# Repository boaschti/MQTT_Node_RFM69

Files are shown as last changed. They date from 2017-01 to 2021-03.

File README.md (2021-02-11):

# RFM69 JSON (Battery)Multisensor
 
This project is a multisensor node based on a Atmega328 and RFM69 radio. The Sensor is a ultraLowPower(0.1uA) device supplied from 1.8V to 3.6V.
 
You can connect the node with the [Gateway](https://github.com/boaschti/MQTT_WLan_RFM69_Gateway) via MQTT to your home automation.
Just download .hex and flash it with avr studio. 
Fuses for use without ext crystal are: low_fuses=0xd2 high_fuses=0xd1 extended_fuses=0xfe (extended_fuses=0xff = BrownOut off = UltraLowPower)
Fuses for use with ext crystal are: low_fuses=0xff high_fuses=0xd1 extended_fuses=0xfe (extended_fuses=0xff = BrownOut off = UltraLowPower). And cut the cooper between RFM and crystal inputs (atmega).

### Board
The board has
- 7 GPIOs including 4 analog inputs
- spi connector
- 3 Leds
- Micro step up via capacitor
- 2 levelshifter or nFet to power sensors ect
- dimensions are 19x22mm
 
The board you can order [here](https://www.itead.cc/) or other PCB Services. You also can send a Email, my price is 0,80€.
 
### Software Features
 
**Supported sensors**
- BME280 BMP280
- DS18b20 (in future)
- HC-SR05 (in future)
- every switch (pir (hc-sr501), touch sensors (TTP223), reed kontakt, hall Sensor (DRV5032FADBZT) ect)
- light sensor (LDR)
- every analog Sernsor (rain sensor, plant sensor, ect)
- S0 energy counter
 
**Supported aktors**
- every aktor which can be used on a DIO
- watchdog can clear/set DOs
- ssd1306 displays
- any electronic thermostat with encoder to set temperature
 
**Software**
- very simple configuration via [Gateway](https://github.com/boaschti/MQTT_WLan_RFM69_Gateway)
- communication encrypted
- free configurable via radio, no flash programming needed, every node has the same software
- interrupts wakes the node
- the DO can be cleared/set by internal watchdog
- counters on each DI
- programmable sleep times
- programmable sensor measure times
- programmable watchdog times
- and more... you can see [here](https://github.com/boaschti/MQTT_WLan_RFM69_Gateway/blob/master/pictures/nodeConfig.jpg)
 
### Home Assistant config
note: use different command_topic (anyChar). The topic from broker to node is rfmOut/networkId/nodeId/anyChar, the topic from node to broker is rfmIn/networkId/nodeId/jsonValue
 
**Temperature, humidity, pressure, battery, rssi, counter(p_0-p_6)**
```
sensor:
  - platform: mqtt
    state_topic: 'rfmIn/146/254/Bt'
    name: 'Temperature'
    unit_of_measurement: '°C'
    value_template: '{{ value_json.Bt }}'
  - platform: mqtt
    state_topic: 'rfmIn/146/254/Bh'
    name: 'Humidity'
    unit_of_measurement: '%'
    value_template: '{{ value_json.Bh }}'
  - platform: mqtt
    state_topic: 'rfmIn/146/254/Bp'
    name: 'Pressure'
    unit_of_measurement: 'hPa'
    value_template: '{{ value_json.Bp }}'
  - platform: mqtt
    state_topic: 'rfmIn/146/254/batt'
    name: 'Battery'
    unit_of_measurement: 'mV'
    value_template: '{{ value_json.batt }}'
  - platform: mqtt
    state_topic: 'rfmIn/146/254/c_4'
    name: 'Counter'
    value_template: '{{ value_json.c_4 }}'
  - platform: mqtt
    state_topic: 'rfmIn/146/254/rxInfo'
    name: 'RSSI'
    value_template: '{{ value_json.rssi }}'
```
 
**Switches (input) p_0-p_6**
```
binary_sensor:
  - platform: mqtt
    state_topic: "rfmIn/146/250/p_5"
    name: "PIR"
    payload_on: "1"
    payload_off: "0" 
    device_class: opening
    value_template: '{{ value_json.p_5 }}'
```
 
**input slider to set temperature of digital termostat**
```
# Define input_slider
input_slider:
  target_temp:
    name: Target Heater Temperature Slider
    min: 5
    max: 30
    step: 1
    unit_of_measurement: step 
    icon: mdi:target
 
automation:
   # This automation script runs when the target temperature slider is moved.
   # It publishes its value to the same MQTT topic it is also subscribed to
   # The message is json format
  - alias: Temp slider moved
    trigger:
      platform: state
      entity_id: input_slider.target_temp
    action:
      service: mqtt.publish
      data_template:
        topic: "rfmOut/146/250/2"
        retain: true
        payload: "{\"t_0\":\"{{ states.input_slider.target_temp.state | int }}\"}"
```
 
**Outputs p_0-p_6**
```
switch:
  - platform: mqtt
    name: "Test Switch"
    state_topic: "rfmIn/146/254/p_4"
    command_topic: "rfmOut/146/254/1"
    payload_on: "{\"p_4\":\"1\"}"
    payload_off: "{\"p_4\":\"0\"}"
    optimistic: false
    retain: true
```
 
**Display**
```
switch:
  - platform: mqtt
    name: "Test Switch"
    command_topic: "rfmOut/146/254/1"
    payload_on: "{\"d_0\":\"Switch ON\"}"
    payload_off: "{\"d_0\":\"Switch OFF\"}"
    optimistic: true
    retain: true
```

**Watchdog**
'''
input_boolean:
  trigger_wd_terrasse:
    name: Watchdog Terrasse
    initial: off
  switch_terrasse_m:
    name: Terrasse m
    initial: off

automation:
  - alias: Trigger Watchdog
    trigger:
      platform: state
      entity_id: input_boolean.trigger_wd_terrasse
      to: "on"
    action:
      - service: mqtt.publish
        data_template:
          topic: "rfmOut/146/116/wd"
          retain: false
          payload: "{\"wd_0\":\"0\"}"
      - service: input_boolean.turn_off
        data: 
          entity_id: input_boolean.trigger_wd_terrasse    
  
  - alias: Trigger Watchdog auto
    trigger:
      platform: time
      seconds: 59
    condition:
      condition: or
      conditions:
        - condition: state
          entity_id: input_boolean.switch_terrasse_vl
          state: "on"
        - condition: state
          entity_id: input_boolean.switch_terrasse_m
          state: "on"
    action:
      service: input_boolean.turn_on
      data: 
        entity_id: input_boolean.trigger_wd_terrasse  
        
  - alias: Start Timer Terrasse m
    trigger:
      platform: state
      entity_id: input_boolean.switch_terrasse_m
      to: "on"
    action:
      service: mqtt.publish
      data_template:
        topic: "rfmOut/146/116/p_5"
        retain: false
        payload: "{\"wd_0\":\"0\", \"p_5\":\"1\"}"

  - alias: Schalte Ventil Terrasse m aus
    trigger:
      platform: state
      entity_id: input_boolean.switch_terrasse_m
      to: "off"
    action:
      service: mqtt.publish
      data_template:
        topic: "rfmOut/146/116/p_5"
        retain: false
        payload: "{\"p_5\":\"0\"}"
'''
### Hardware
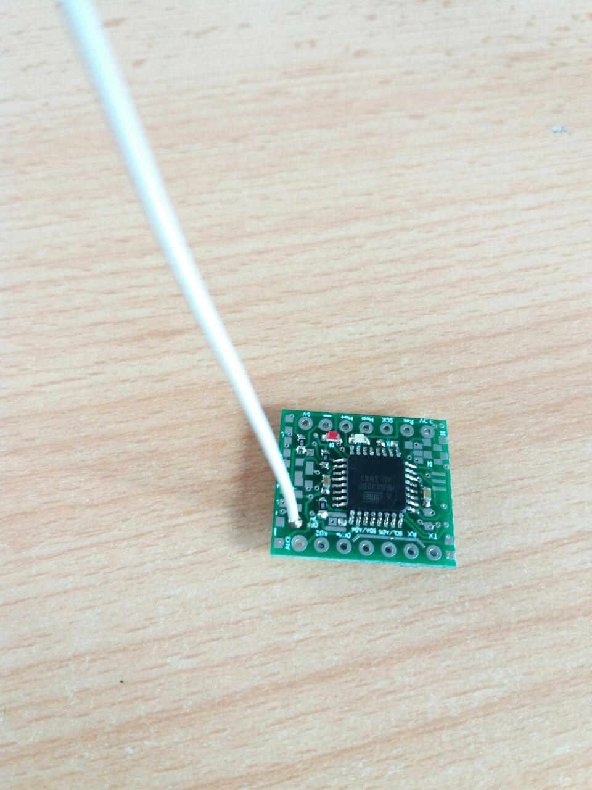
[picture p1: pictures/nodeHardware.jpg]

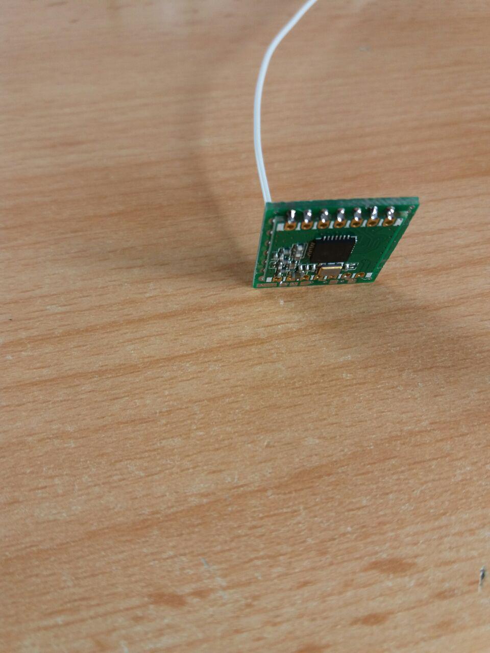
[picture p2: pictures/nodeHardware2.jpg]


### Housing

**3AAA_PIR_Node**
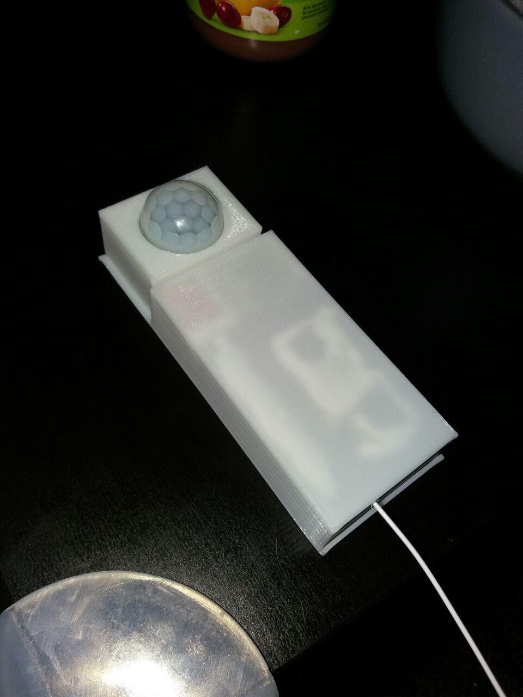
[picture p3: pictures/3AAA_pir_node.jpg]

 
**3AAA_PIR_Node inside, modification PIR (nFet or diode bat46 4148 ect)**

 
**2AAA_Node**
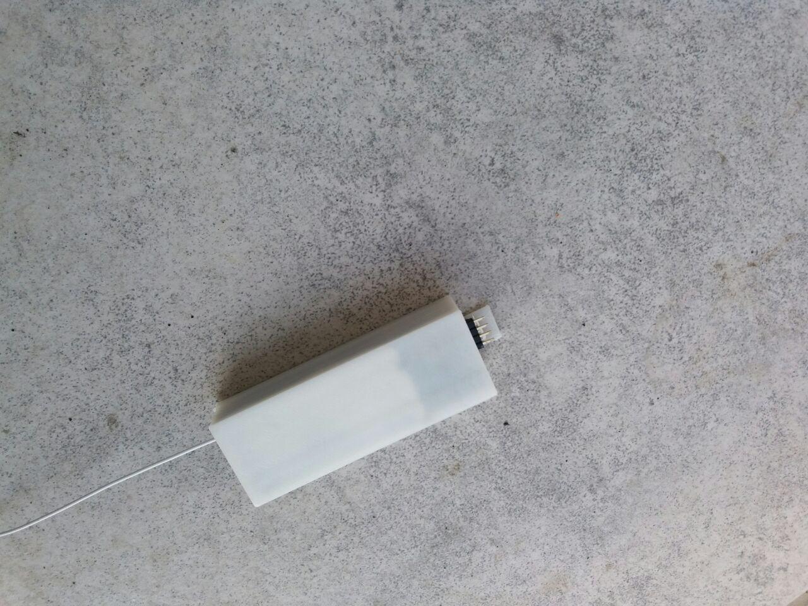
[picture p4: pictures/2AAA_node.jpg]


**2AAA_Node_inside**
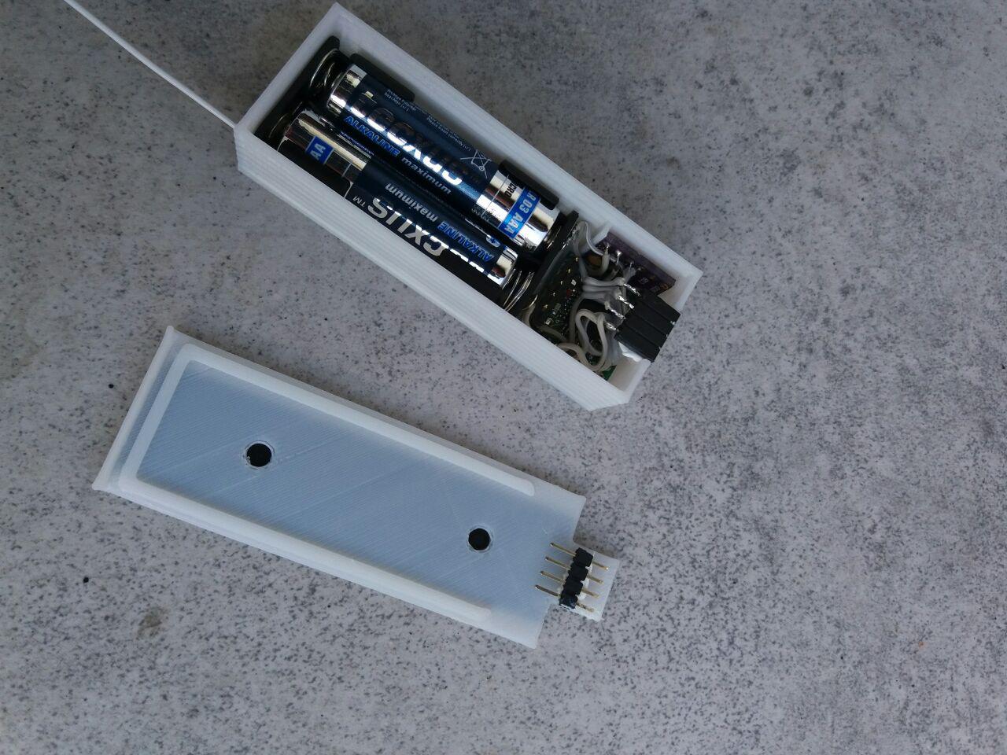
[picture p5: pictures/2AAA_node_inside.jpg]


**Display_housing**
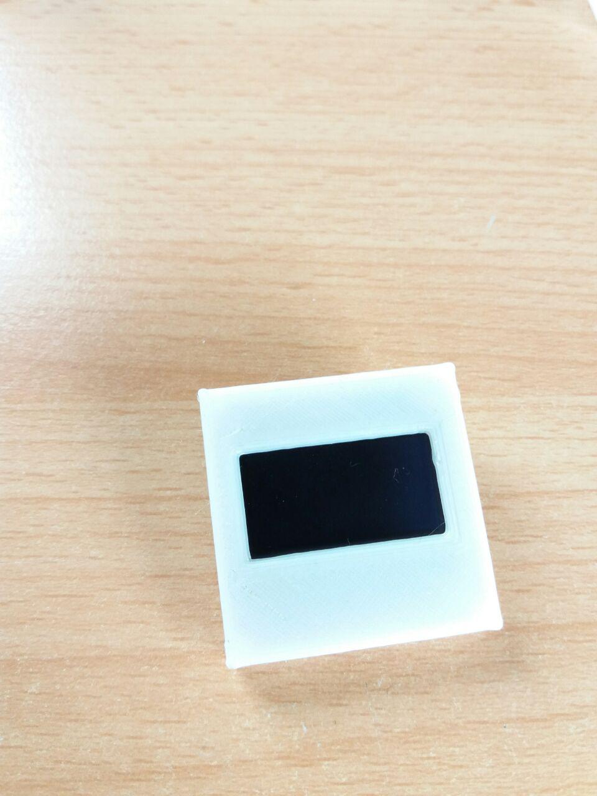
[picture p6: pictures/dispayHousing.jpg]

 
**Mini_Node_1**
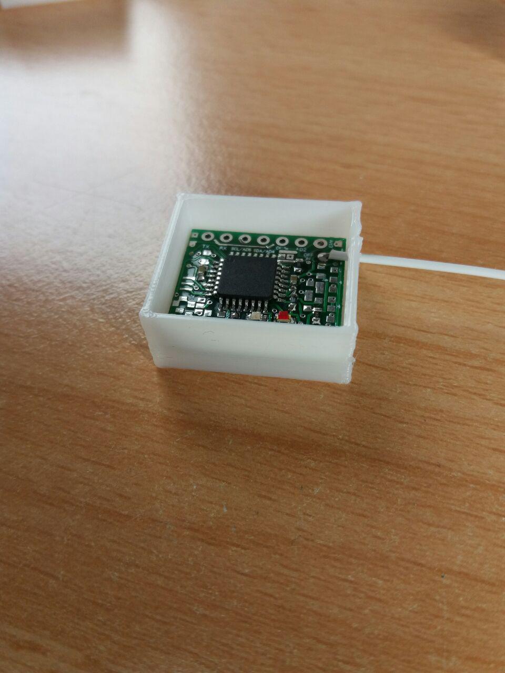
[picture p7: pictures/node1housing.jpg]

 
**Mini_Node_2 use the shown BME/BMP Sensor!**
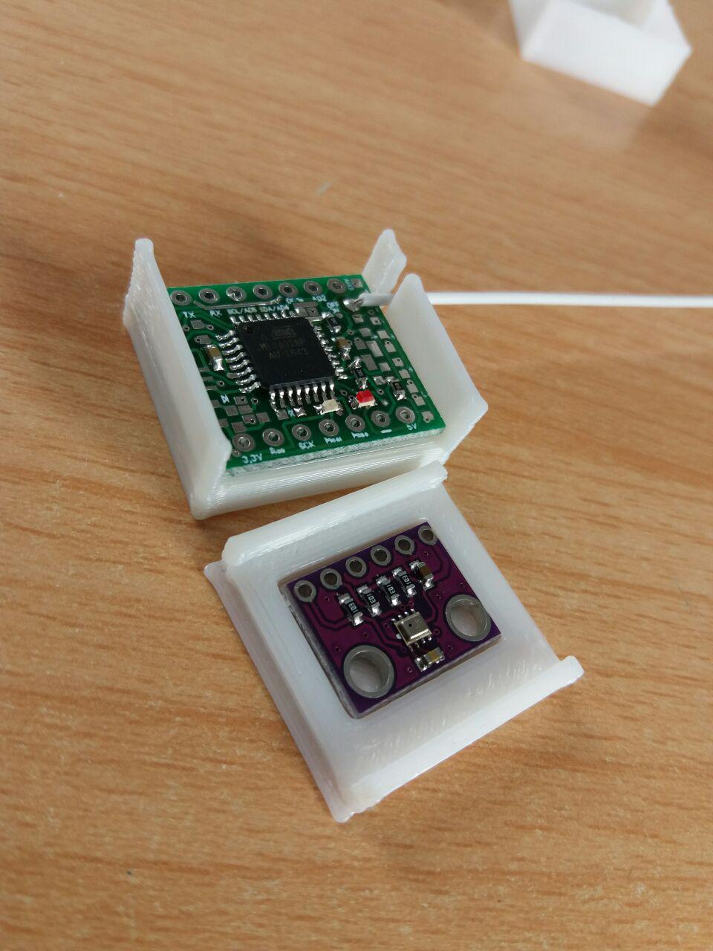
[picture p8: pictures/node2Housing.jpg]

 
**Modification_Display**
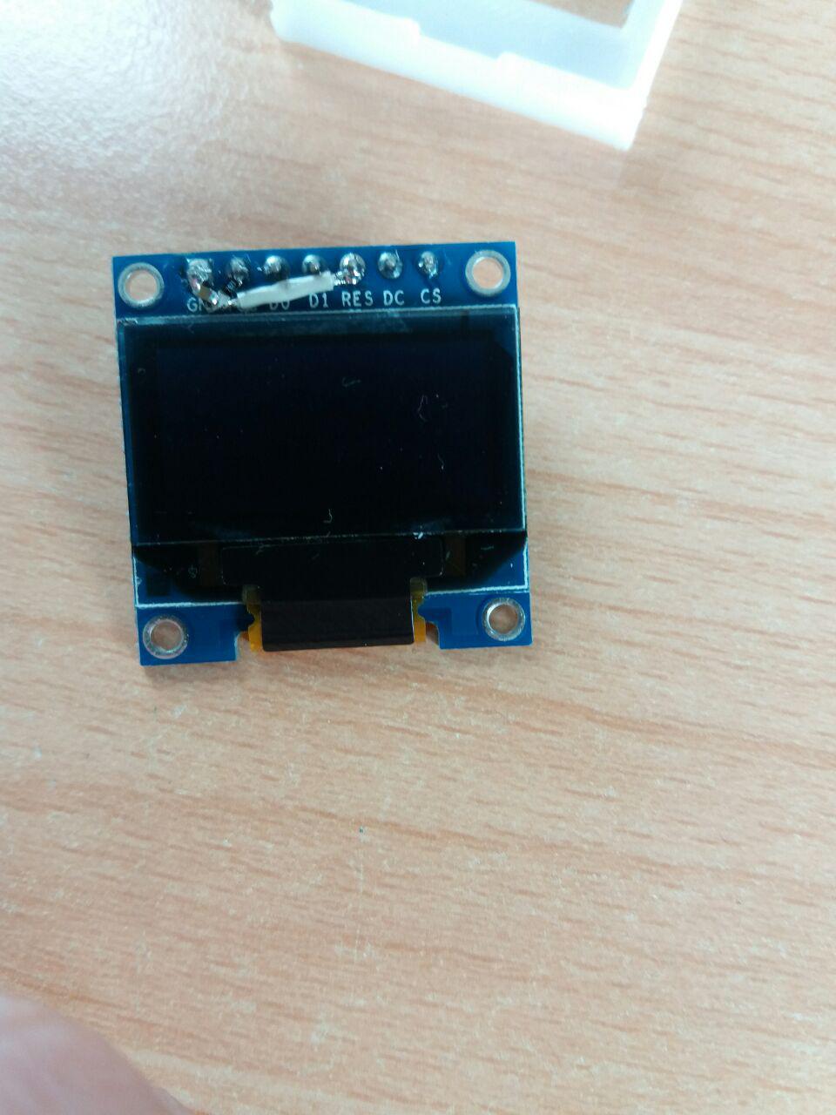
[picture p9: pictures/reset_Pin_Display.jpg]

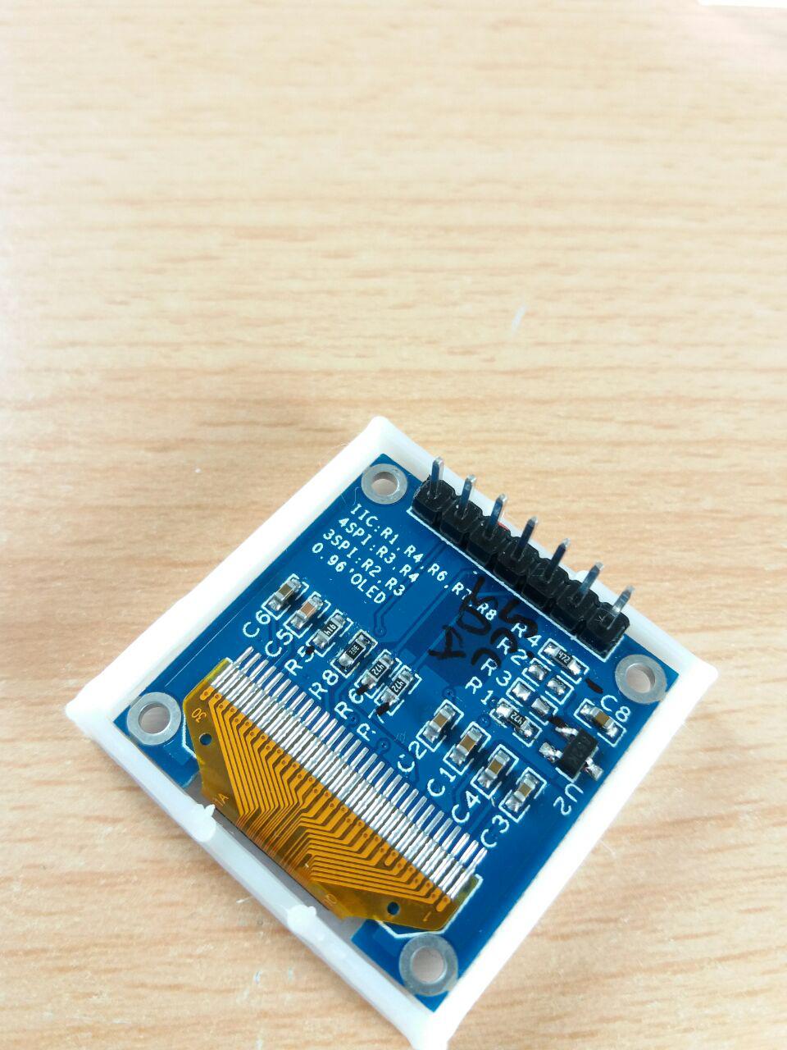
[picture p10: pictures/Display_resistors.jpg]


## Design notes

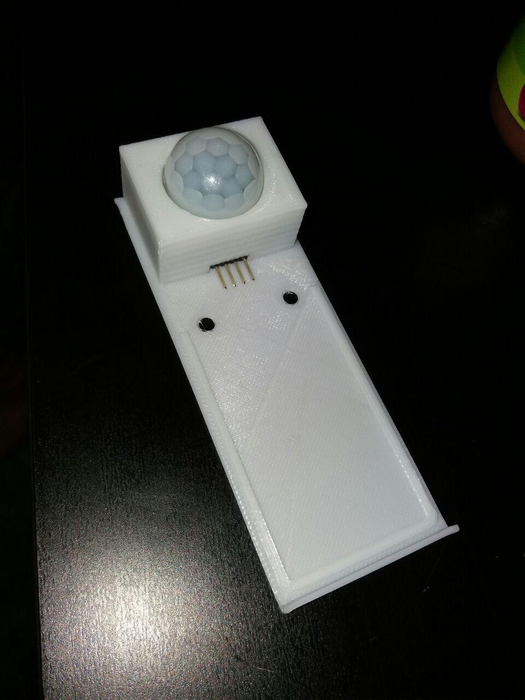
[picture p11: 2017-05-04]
pictures/pir_node.jpg

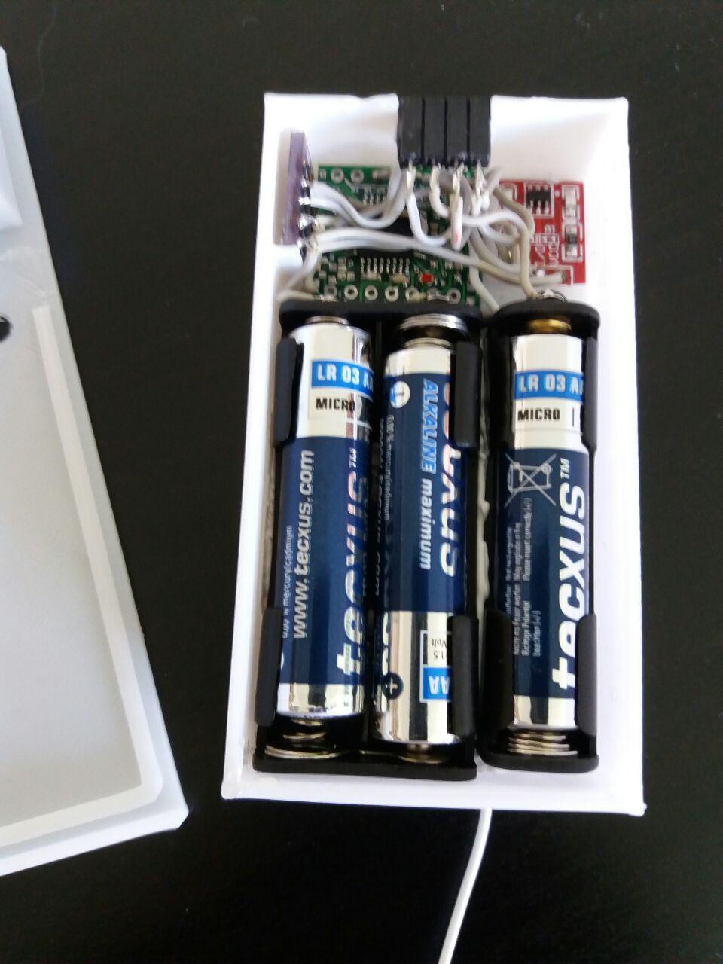
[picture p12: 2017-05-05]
pictures/3AAA_pir_node_inside2.jpg

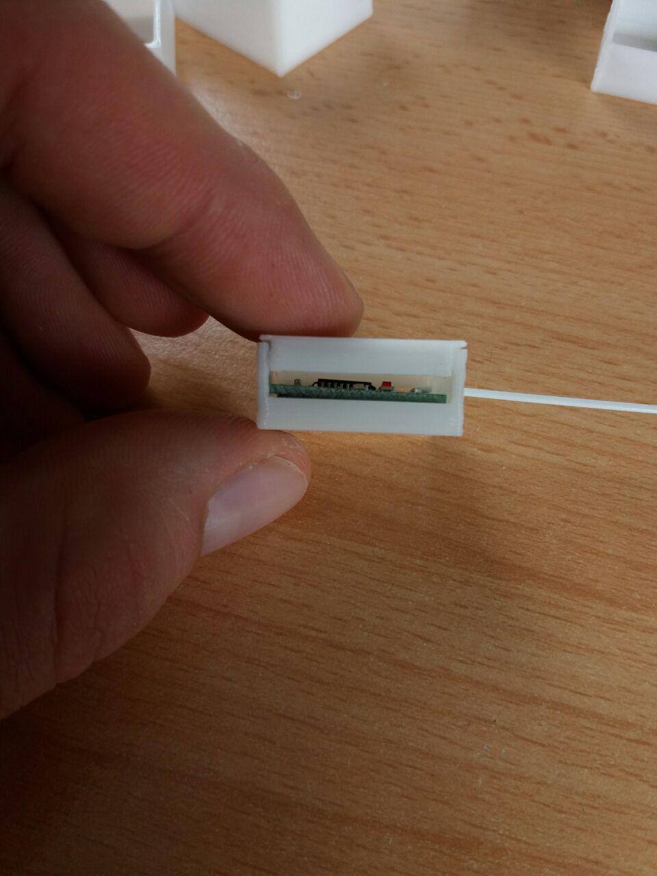
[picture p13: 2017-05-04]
pictures/node2Housing2.jpg

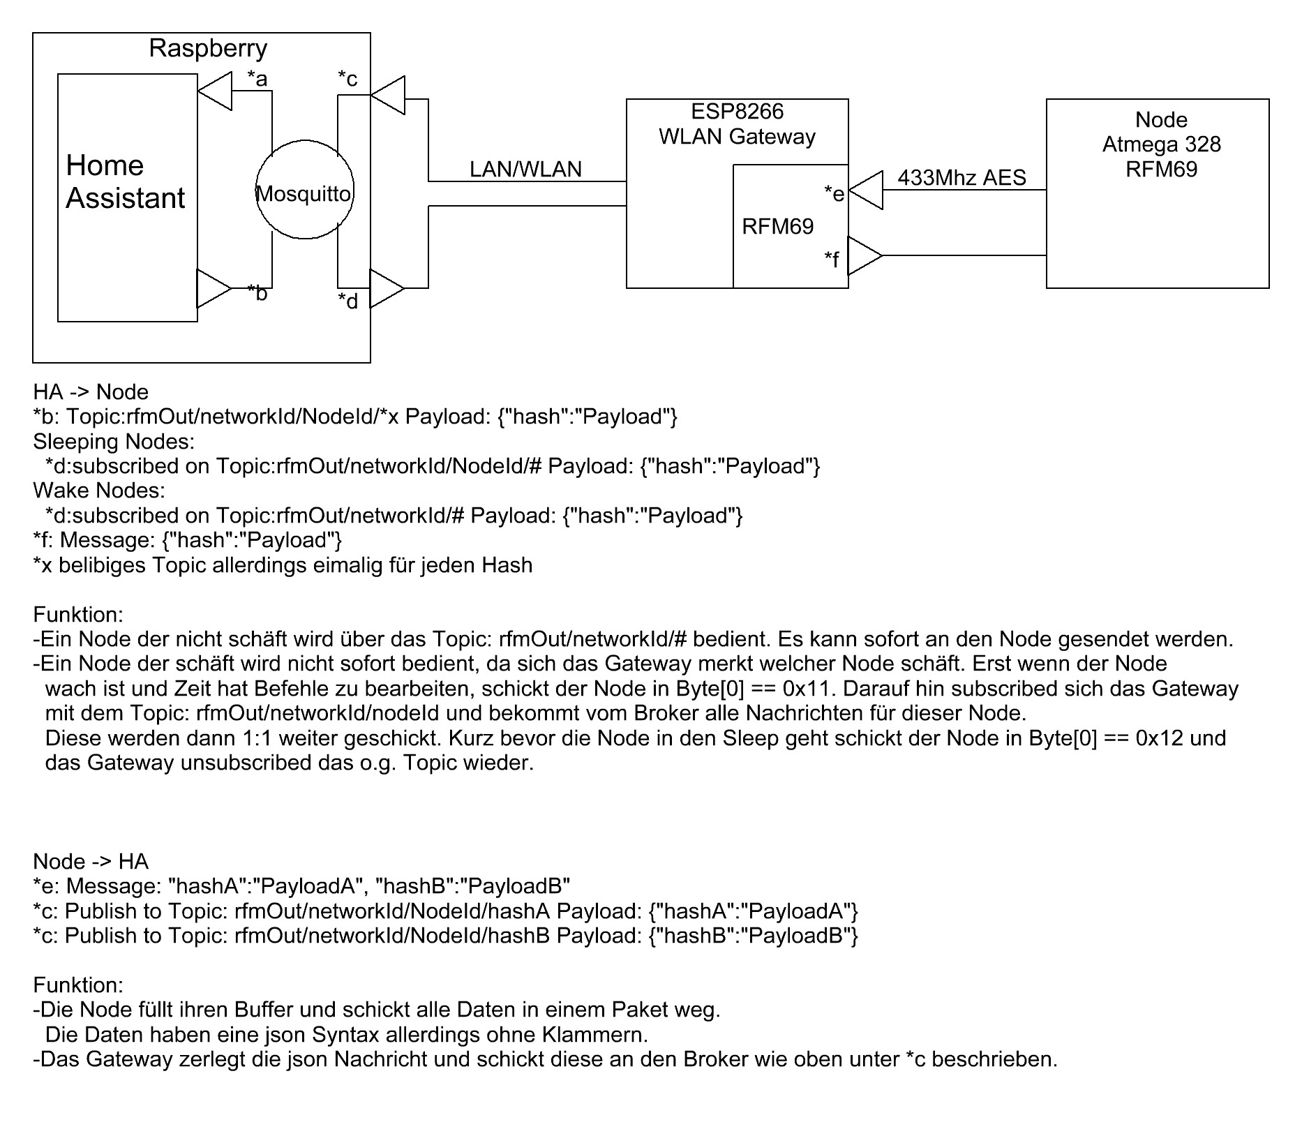
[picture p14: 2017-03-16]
Kommunikation.JPG

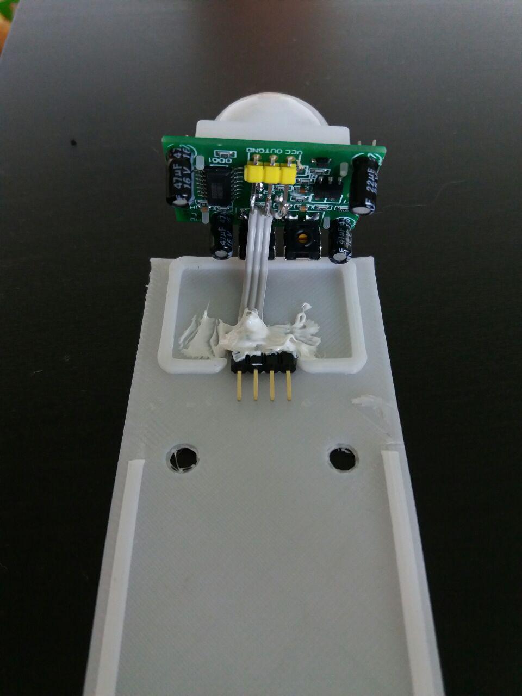
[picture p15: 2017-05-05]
pictures/pir.jpg

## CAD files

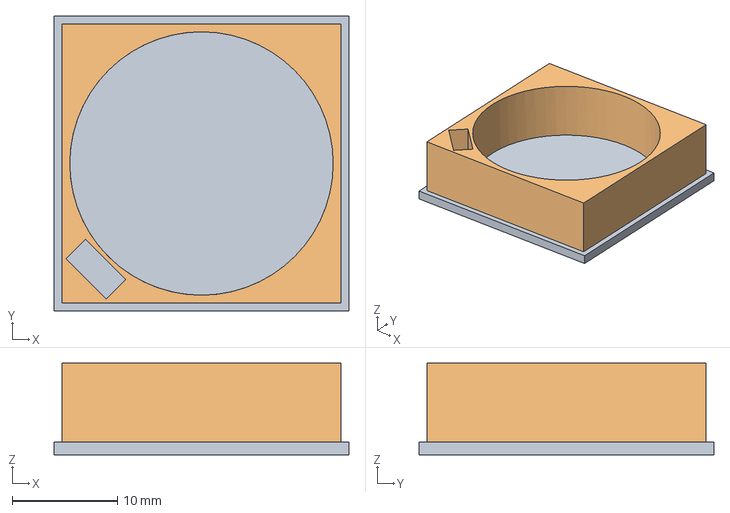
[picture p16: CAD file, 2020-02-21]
Housing/Deckel_CR2477_Node.FCStd
28.0 x 28.0 x 8.70 mm
Würfel001

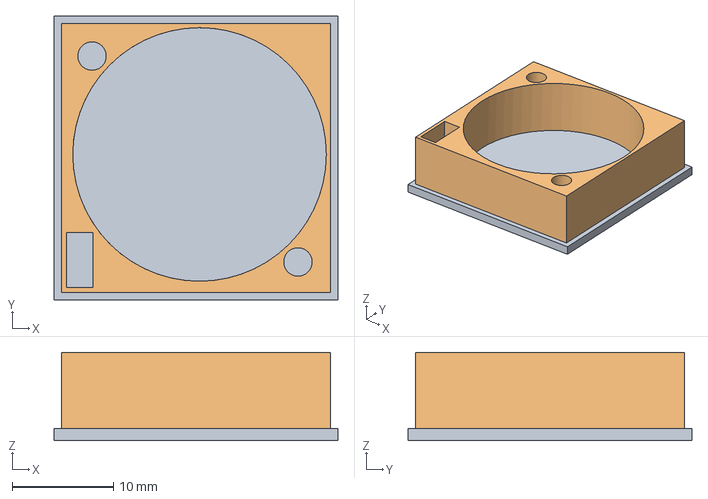
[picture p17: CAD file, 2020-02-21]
Housing/Deckel_CR2477_Node2.FCStd
28.0 x 28.0 x 8.70 mm
Würfel001

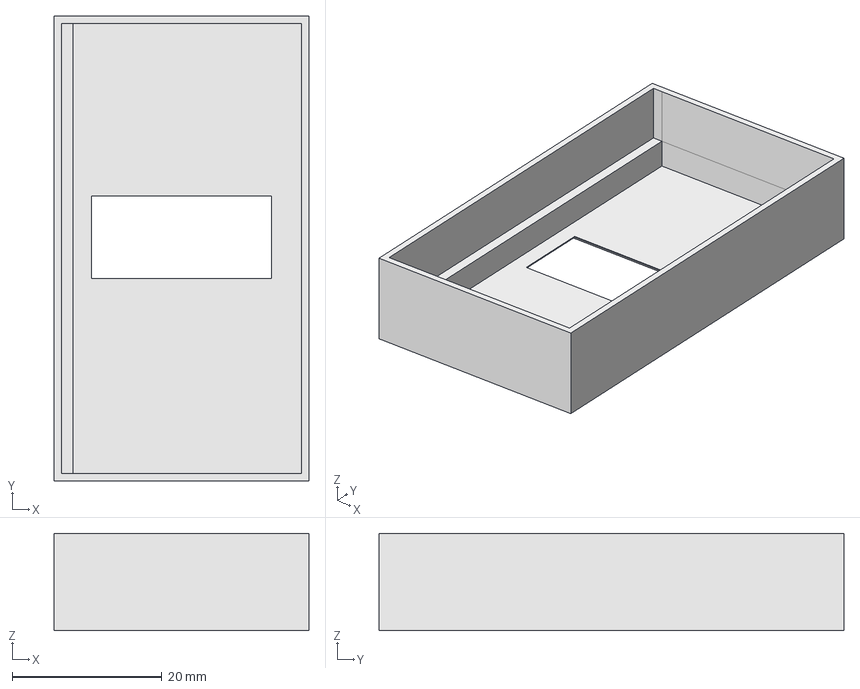
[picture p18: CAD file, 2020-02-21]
Housing/MaxiNodeDisp_Touch.FCStd
34.0 x 62.0 x 13.0 mm

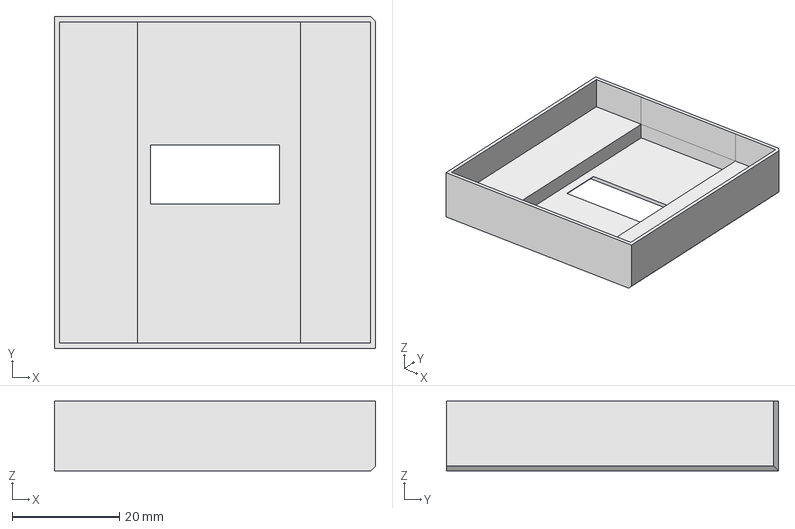
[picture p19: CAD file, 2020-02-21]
Housing/MaxiNodeDisp_Touch_AAA.FCStd
60.0 x 62.0 x 13.0 mm

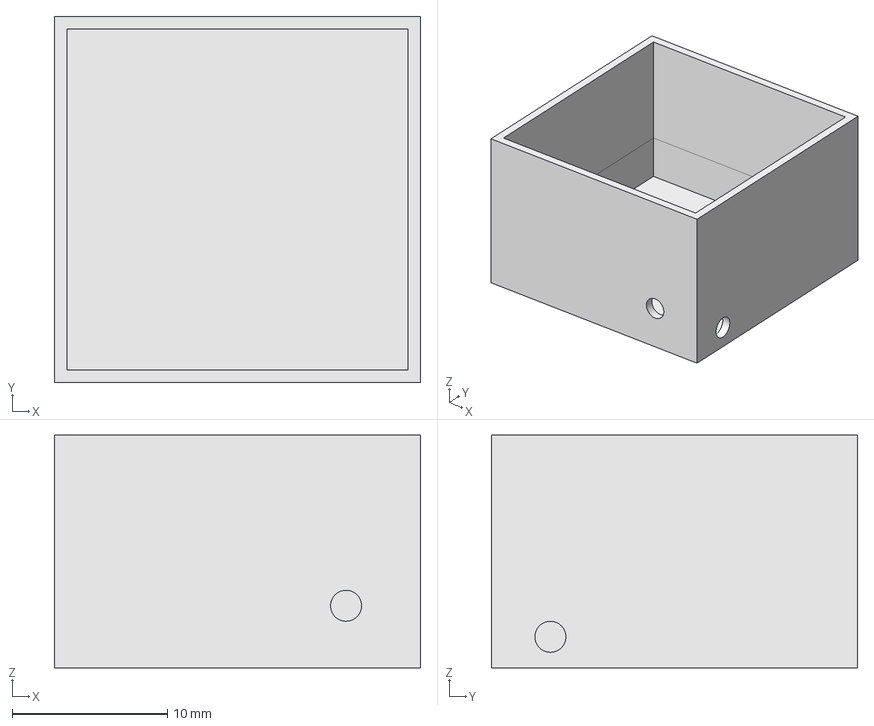
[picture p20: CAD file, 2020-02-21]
Housing/Gehause Node3.FCStd
23.6 x 23.6 x 15.0 mm

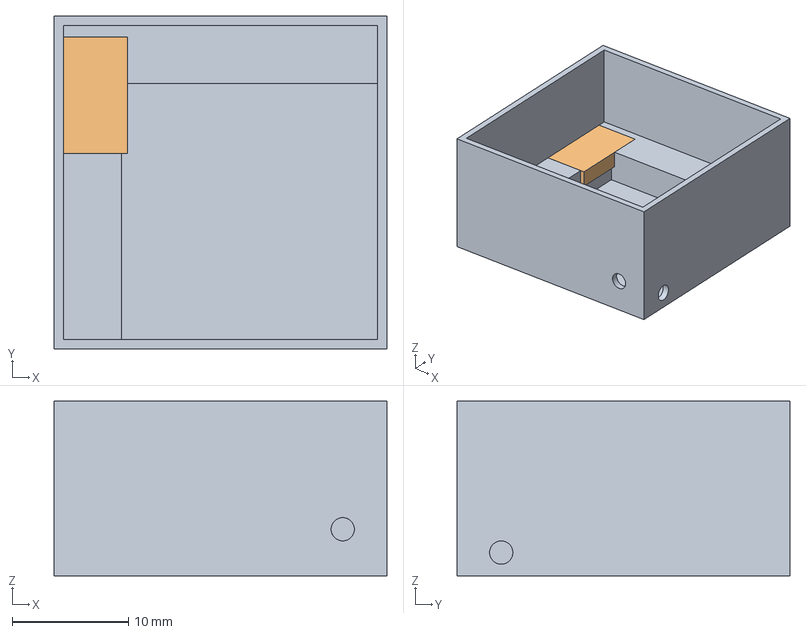
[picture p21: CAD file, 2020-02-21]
Housing/Gehause_CR2477_Node.FCStd
28.6 x 28.6 x 15.0 mm
Würfel003

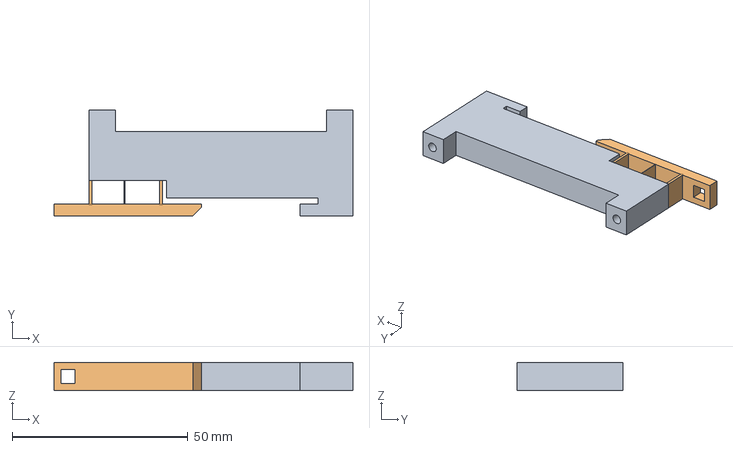
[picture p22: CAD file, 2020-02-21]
Housing/Halter Hutschine Relais.FCStd
85.0 x 30.0 x 8.00 mm

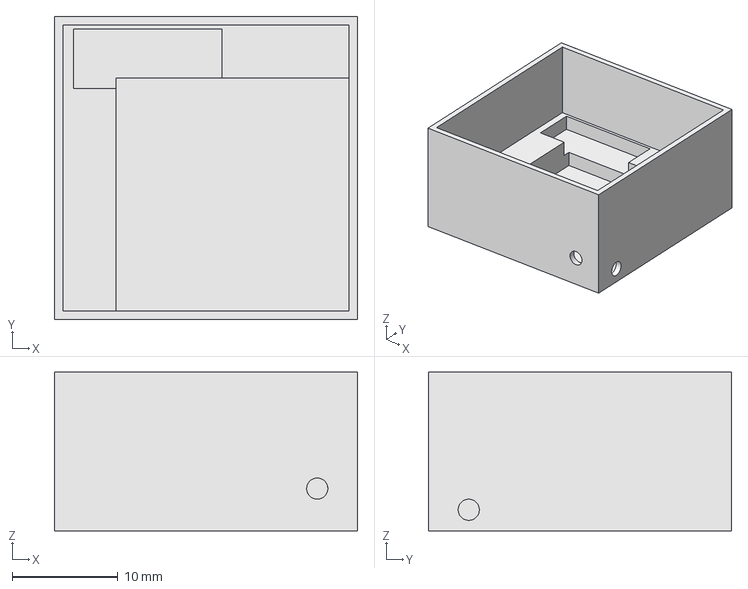
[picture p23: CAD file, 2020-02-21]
Housing/Gehause_CR2477_Node2.FCStd
28.6 x 28.6 x 15.0 mm

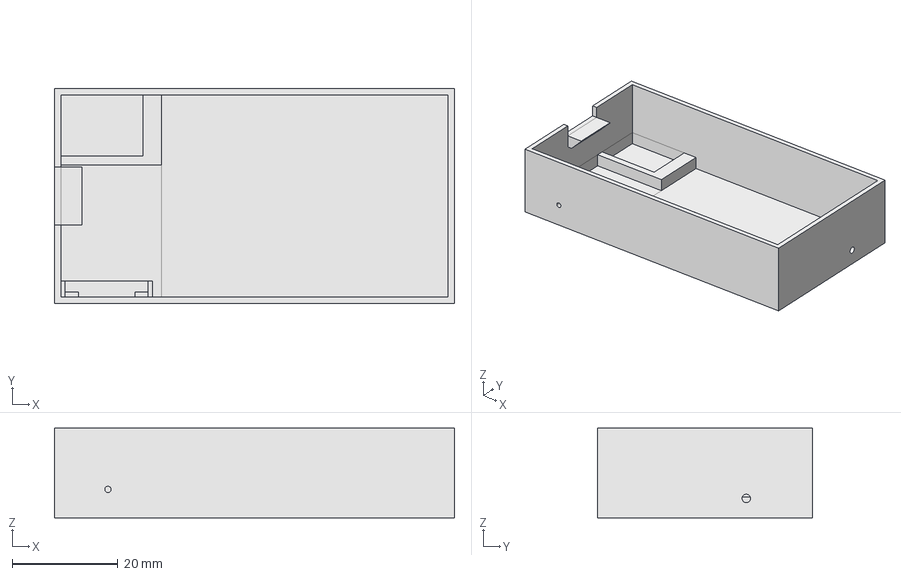
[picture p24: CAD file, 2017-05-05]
Housing/Gehause_3AAA_Node.FCStd
75.6 x 40.6 x 17.0 mm

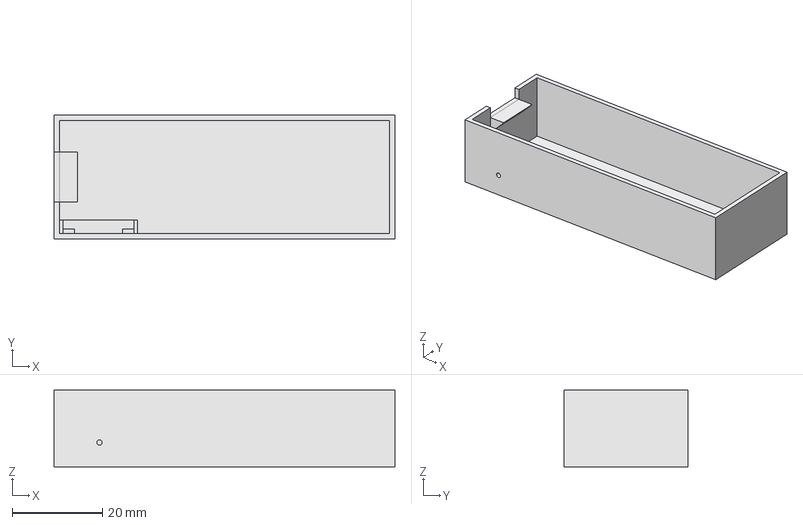
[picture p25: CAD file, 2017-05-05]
Housing/Gehause_2AAA_Node.FCStd
75.6 x 27.5 x 17.0 mm

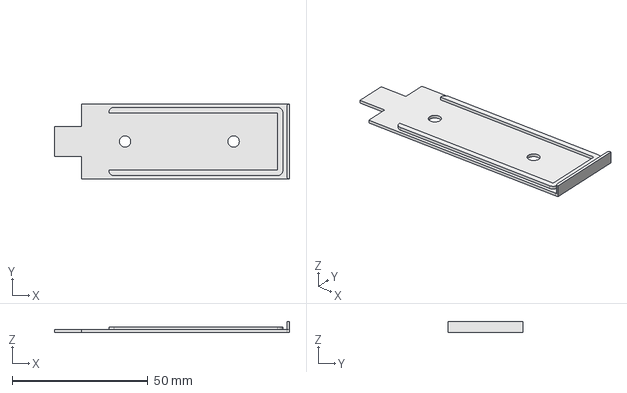
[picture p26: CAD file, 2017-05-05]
Housing/Deckel_2AAA_Node.FCStd
86.6 x 27.5 x 4.00 mm

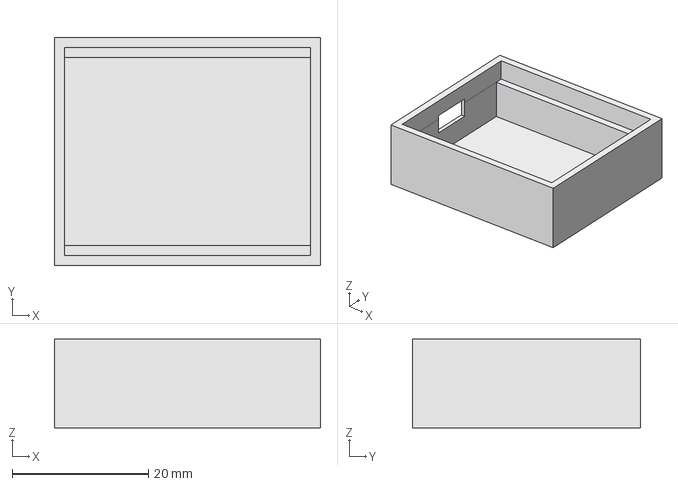
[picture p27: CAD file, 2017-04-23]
Housing/Gehause 4x4Led WEMOS Panel.FCStd
39.0 x 33.5 x 13.0 mm

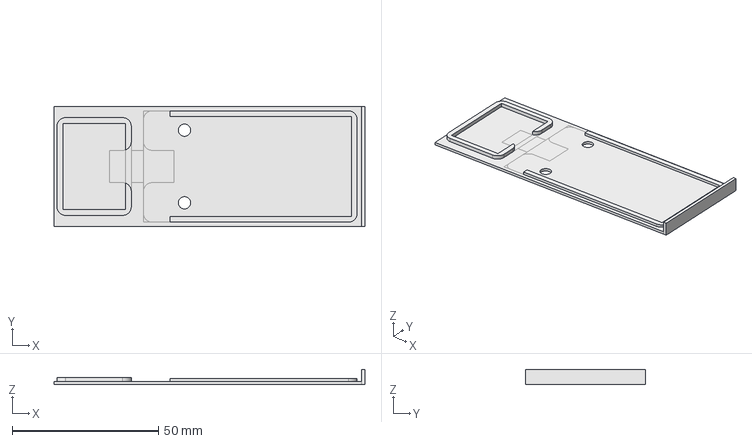
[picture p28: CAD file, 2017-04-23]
Housing/Deckel_3AAA_PIR_Node.FCStd
106.2 x 41.0 x 5.00 mm

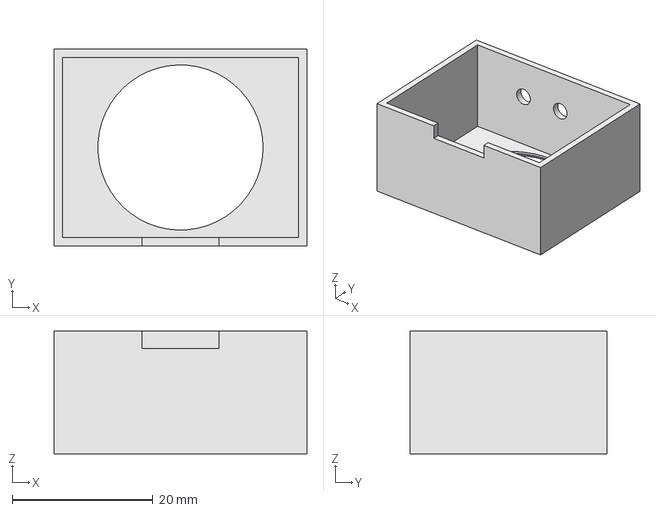
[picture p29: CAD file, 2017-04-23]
Housing/Gehause HC-SR501.FCStd
36.0 x 28.0 x 17.5 mm

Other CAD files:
Housing/Deckel_2AAA_PIR_Node.FCStd
Housing/Gehause Display.FCStd
Housing/Deckel Node2.FCStd
Housing/Deckel Display.FCStd
Housing/Deckel Display.stl
Housing/Deckel Node1.FCStd
Housing/Deckel Node1.stl
Housing/Deckel Node2.stl
Housing/Deckel_2AAA_Node.stl
Housing/Deckel_3AAA_PIR_Node.stl
Housing/Deckel_CR2477_Node.stl
Housing/Gehause 4x4Led WEMOS Panel.stl
Housing/Gehause Display.stl
Housing/Gehause HC-SR501.stl
Housing/Gehause Node1.FCStd
Housing/Gehause Node1.stl
Housing/Gehause Node2.FCStd
Housing/Gehause Node2.stl
Housing/Gehause_2AAA_Node.stl
Housing/Gehause_3AAA_Node.stl
Housing/Gehause_CR2477_Node.stl
Housing/Halter Hutschine Relais.stl
Housing/MaxiNodeDisp_Touch.stl

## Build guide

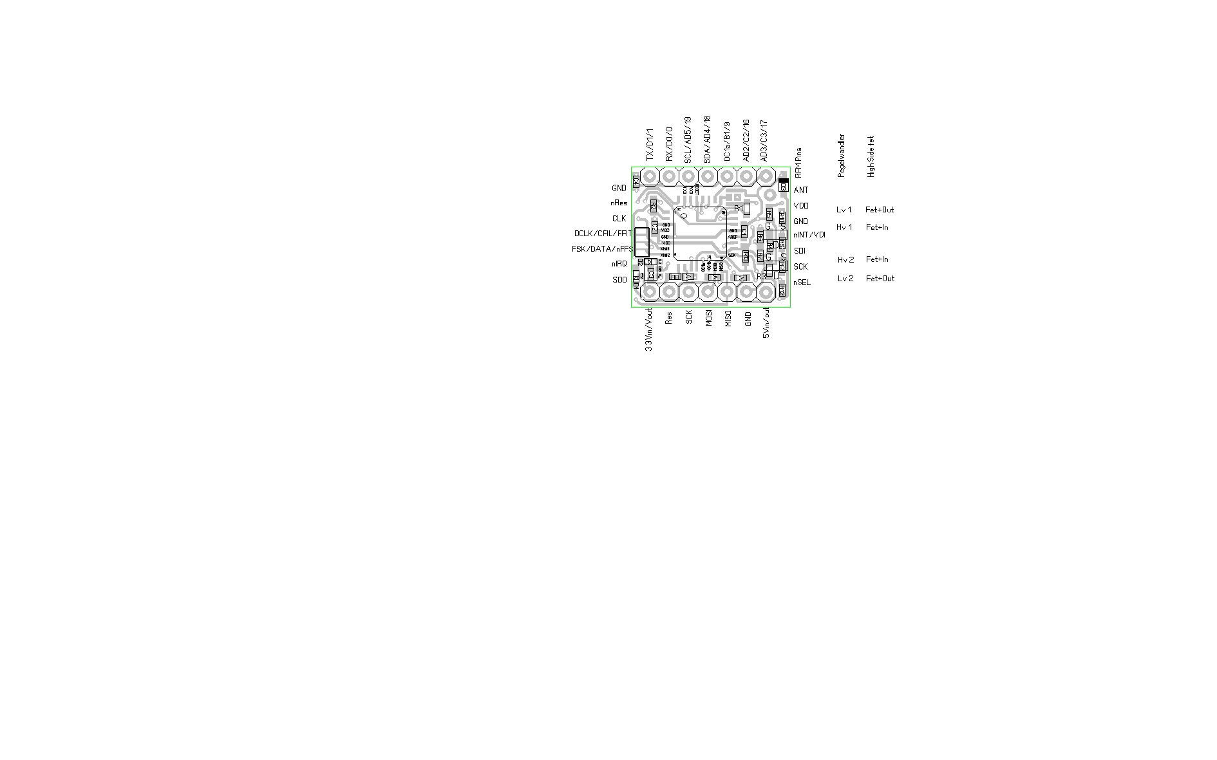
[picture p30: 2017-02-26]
Board V2.0/mini Node/RS232FunkV2.0obenPrintVersion.jpg

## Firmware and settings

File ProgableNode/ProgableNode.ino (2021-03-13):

/*
Author:  Sebastian Weisser
Date 28.01.2017
Modifications Needed:
1)  Update encryption string "ENCRYPTKEY"
2)  Frequency setting
*/


//Board defines  --------------------------------------------------------------------------------------------------
#define ArduinoSPSNode
//#define InternalOszilator


#ifdef ArduinoSPSNode
  #define RF69_SPI_CS          5
#else 
  #define RF69_SPI_CS          8
#endif
  

//Basic Defines  --------------------------------------------------------------------------------------------------
#include "RFM69.h"
#include <SPI.h>
#include <avr/sleep.h>
#include <avr/wdt.h> 
#include "RFM69registers.h"
#include <avr/power.h>

#define Commit "cc971da"


//Standardkonfig wird uebernommen wenn JP_2 == GND oder funktion_pin0 == 255 (Komando "w_0":"255")
#define DEFAULTNODEID        254                    //nur einmal im Netzwerk vorhanden
#define DEFAULTNETWORKID     1                      //bei allen Nodes im Netzwerk gleich
#define DEFAULTGATEWAYID     1      
#define DEFAULTENCRYPTKEY    "sampleEncryptKey"     //exakt 16 Zeichen, gleich auf allen Nodes in diesem Netzwerk

//Frequenz vom RFM Modul
#define FREQUENCY   RF69_433MHZ
//#define FREQUENCY   RF69_868MHZ
//#define FREQUENCY     RF69_915MHZ
//#define IS_RFM69HW    //uncomment only for RFM69HW!
#define ACK_TIME		30 // Wartezeit auf einen ACK

#define ResetRfmPin		2
#define rxPollTime		450           // Zeit in ms (ca) die auf eine Message gewartet wird bevor der Node in den Sleep geht
#define timemultiplierWD 5000UL       // ms 
#define timemultiplierSensor 10000UL  // ms 

#define JP_1		  16 //PC2 
#define JP_2		  15 //PC1
#define RFM_POWER_LEVEL 31




RFM69 rfm69;



//end Basic Defines ---------------------------------------------------------------------------------------------------


//Board Defines--------------------------------------------------------------------------------------------------------
#include <OneWire.h>
#include <DallasTemperature.h>
#include <Adafruit_Sensor.h>
#include "Adafruit_BME280.h"
#include <U8x8lib.h>

#ifndef ArduinoSPSNode
  #define InternalOszilator
#endif

#ifdef InternalOszilator
  #define F_CPU 4000000UL
#endif


//U8X8_SSD1306_64X48_ER_HW_I2C u8x8(/* reset=*/ U8X8_PIN_NONE);  
U8X8_SSD1306_128X64_NONAME_HW_I2C u8x8(/* reset=*/ U8X8_PIN_NONE);  

//device DS18B20
    #define ONE_WIRE_BUS 9
    OneWire oneWire(ONE_WIRE_BUS);
    DallasTemperature dallas(&oneWire);
    
//BME280 I2C
    #define SEALEVELPRESSURE_HPA (1013.25)
    Adafruit_BME280 bme;
    
//Pins zum versorgen der Sensoren
    #define pumpPin			5
    //#define supplyPin		6
    #define supplyPin		17 //AD3
    
//Pins zum bedienen des Heiz Thermostat Stellrades
    #define signalA         0
    #define signalB         1    
   

//device ultrasonic
    #define HC05pingPin 	0
    #define HC05trigPin		1

  
//device FuelHigh Sensor 

    #define PumpXtimes    2
    #define AirPumpPin    0
    
//ADC Hysterese für das automatische senden des ADC Wertes

    #define adcHysterese 0x0032
    
    
#define SERIAL_BAUD 9600


unsigned long WatchdogPeriod;
unsigned long SensorPeriod;
volatile unsigned long WdTrigTimeStamp;
unsigned long WdPinTimeout;
volatile boolean SleepAlowed;
volatile boolean BreakSleep = false;
volatile boolean PCinterrupt = false;
volatile boolean InputAlredyRead = false;

volatile boolean SendAlowed = true;

volatile boolean ThermostatPresent = false;
volatile boolean ShowLeds = false;

bool wdMsgSend = false;

//end Board Defines ---------------------------------------------------------------------------------------------------


#define configSize 31
#define configSizeInternal 2
#define configSizeAll configSize + configSizeInternal

uint8_t eeConfig[configSizeAll] EEMEM;
volatile uint8_t config[configSizeAll];
uint8_t eeEncryptKey[16+1] EEMEM;


//Folgende Definitionen zeigen die Bit stellen der einstellbaren Funktionen.
//Die Standard Einstellungen koennen mit dem setzen von config[0] hergestellt werden.
//Es koennen folgende  Eigenschaften fuer die Pins eingestellt werden:

//Bits der Variablen funktion_pin..
#define in_out          0           //DDR wie im Atmel Datenblatt 0=in
#define port            1           //PORT wie im Atmel Datenblatt 1=High(im outputMode)/1=Pullup(im inputMode) sowie zustand in den der Port bei ablaufen des WD faellt
#define intRise         2           //Der Pin loest einen Interrupt aus (aufwachen aus dem Sleep und sofortiges lesen des Pins wenn readInput gesetzt ist)
#define intFall         3           //todo Der Pin gibt ein software PWM Signal aus
#define free            4           
#define wdReq           5           //Watchdog fuer diesen Pin aktivieren
#define readInput       6           //Ruecklesen des Pins und senden der Daten (polling fuer Interrupt pcInt setzen)
#define count           7           //Wenn die anzahl der Schaltvorgaenge gezaehlt werden soll

//Zum konfigurieren der analog Inputs muss man angeben wie der Wert verrechnet wird.
//Bits der Variablen math_analog..
#define readPlant       0           //Arduino Pflanzen Feuchte Sensor (untested)
#define readLDR         1           //Photo Widerstand 10k pulldown
#define readFuelHigh    2           //Honewell ABPDANT005PGAA5 Staudruck wasser umgerechnet in cm
#define readRaw         3           //raw adc Wert
#define readVolt        4           //reads voltage of a ADC
#define multi2         5            //multiply ADC / 2 
#define multi4         6            //multiply ADC / 4 

//Zum konfigurieren der digitalen Sensoren muss man nur angeben welche Sensoren gelesen werden sollen.
//Bits der Variable digitalsensors
#define readDS18        0           //(Pins s. defines ONE_WIRE_BUS)
#define readHC05        1           //Ultraschall Sensor (Pins s. defines HC05pingPin und HC05trigPin)
#define readBME         2           //BME280 und BMP280 (Standart I2C Pins)
#define debounceLong    3           //Wenn ein Schalter lang prellt muss ein extra langer debounce ausgeführt werden


//Zum kofigurieren von digitalen Aktoren muss man nur angeben welche Aktoren verbaut sind.
//Bits der Variable digitalOut
#define lockThermostate 0           //Lock the encoder of a thermostate
#define uart            1
#define free2           2           
#define ssd1306_64x48   3           //WEMOS Schield mit ssd1306 und 64x48 Pixel, SCL:D1 SDA:D2 VDD:3V3 GND:GND
#define ssd1306_128x64  4           //Display Board mit ssd1306 und 128x64 Pixel, Board mit 7 Pins: R1,R4,R6,R7:4,7k R8:0 SCL:D0 SDA:D1 VDD:3V3 GND:GND,DC RES*
//     100nF 10k
//GND---||---[__]---VDD
//         |________RES*

//Zum einstellen des Verhaltens der Node:
//Bits der Variable nodeControll
#define sensorPower         0       //der supplyPin (5) wird zum Versorgen von Sensoren und fuer die LED2 verwendet. Wenn 0 dann nur fue die LED2.
#define pumpSensorVoltage   1       //der pumpPin (6) wird zum verdoppeln der Betriebsspannnung fuer Sensoren verwendet indem ein Kondensator aufgeladen wird. Sowie fuer die LED1. Wenn 0 dann nur fue die LED1.
#define sensorPowerSleep    2       //die Sensor versorgung wird waehrend dem Sleep nicht abgeschaltet. Wenn pumpSensorVoltage gesetzt ist wird alle 8sec der Kondensator erneut aufgeladen.
#define debugLed            3       //schaltet die Led Status anzeigen 
#define displayAlwaysOn     4       //Das Display wird im sleep nicht abgeschaltet
#define delOldData          5       //Die alten Daten die evtl nicht gesendet wurden werden in einem neuen Aufwachzyklus geloescht
#define sendAgain           6       //Die alten Daten die evtl nicht gesendet wurden werden nach einem wd Zyklus (8s) erneut gesendet
#define displayLongOn       7       //Das Display wird 40 sec nach dem Einschlafen aktiv gehalten

//Einstellen von Verhalten aufgrund externer Hardware
#define extCrystal          0       //Wenn ein externer Quarz verbaut ist Fuse: L 0xFF H 0xD1 E 0xFF Wichtig: Leiterbahn zum RFM Unterbrechen damit osc eingang frei schwingen kann

//Die folgenden Definitionen zeigen die Stelle im BYTE Array wo die Einstellungen gespeichert sind:
//Man kann direkt auf das ARRAY per Funk zugreifen die Werte sind immer dezimal:
//"w_5":"3" -> Zum Schreiben einer 3 an Stelle 5
//"r_5":"3" -> Zum Lesen der Stelle 5 (die "3" wird gebraucht allerdings ignoriert)
//"p_5":"1" -> Zum setzen und ruecksetzen des Ports 5 (funktion_pin..)
//"d_5":"ABC123" -> Zum schreiben eines Strings auf das Display. 5 ist die Zeilen Nummer

//Bytes des Config Arrays
//Anordnung wie auf der Leiterplatte
#define  funktion_pin1          0
#define  funktion_pin0          1
#define  funktion_pin19         2
#define  funktion_pin18         3
#define  funktion_pin9          4
#define  funktion_pin16         5
#define  funktion_pin17         6

#define  math_analog2           10
#define  math_analog3           11
#define  math_analog4           12
#define  math_analog5           13

#define  digitalSensors         15
#define  digitalOut             16

#define  chipSetup              19
#define  nodeControll           20
#define  sleepTimeMulti         21    //sleepTime Multiplikator
#define  sleepTime              22    //Sleep time in Sekunden * 8 sec, Wenn der Timer gesetzt ist wird auch die Batteriespannung gemessen
#define  watchdogTimeout        23    //watchdog in * 8 sec, Zeit bis zum abfallen des Watchdogs und setzen der Pins auf den vorgegebenen Zustand (port). Der Sleep wird gesperrt wenn der Watchdog nicht abgefallen ist.
#define  watchdogDelay          24    //watchdog in * 5 sec, Zeit bis zum nachsten senden eines Watchdogs (Nur wenn sleepTime == 0 konfiguriert ist oder der watchdog durch staendiges Nachtriggern den Sleep blokiert. Ansonsten wird der Watchdog sofort nach dem Aufwachen gesendet wenn watchdogDelay>0)

#define  contrast               26
#define  nodeId                 27    //NodeId dieses Sensors (einzigartig im Netzwerk)
#define  networkId              28    //NetworkID dieses Sensors (alle gleich im Netzwerk)
#define  gatewayId              29    //GatewayID an diese Addresse werden die Daten geschickt und es werden nur Daten von dieser Addresse beruecksichitgt. Sollten Daten von einer Anderen Adresse kommen werden sie an das Gateway weitergeleitet.
#define  sensorDelay            30    //Messpause der Sensoren in * 10 sec (Nur wenn sleepTime == 0 konfiguriert ist oder der watchdog durch staendiges Nachtriggern den Sleep blokiert)
#define  firstEEPromInit        31    //internal
#define  oscCalError            32    //internal

//In den folgenden Definitionen ist das PinMapping beschrieben: fur digtal IOs config[0]:config[9], fur analog Is config[10]:config[14].
#ifndef ArduinoSPSNode
  #define usedDio                 7       //Anzahl der verwendetetn DIOs
  #define usedAnalog              4       //Anzahl der verwendetetn analog In
  #define offsetAnalogConfig      10      //offset der analogen konfig
  const uint8_t pinMapping[15]{1,0,19,18,9,16,17,0,0,0,2,3,4,5,0};
  //der SSPin macht noch Probleme Spi funktioniert dann nicht mehr!
  //const uint8_t pinMapping[15]{0,1,17,18,19,9,10,0,0,0,3,4,5,0,0};
  unsigned long counter[usedDio];
  const uint8_t LedPinMapping[3]{5,6,7};
#else
  #define usedDio                 10       //Anzahl der verwendetetn DIOs
  #define usedAnalog              6       //Anzahl der verwendetetn analog In
  #define offsetAnalogConfig      9      //offset der analogen konfig
  const uint8_t pinMapping[15]{15,16,17,18,19,6,7,8,9,1,2,3,4,5,6};
  //der SSPin macht noch Probleme Spi funktioniert dann nicht mehr!
  unsigned long counter[usedDio];
  const uint8_t LedPinMapping[3]{0,0,0};
#endif
// Typische Led Farben: 0:Gruen 1:Gelb/Org 2:Rot

#define bit_set(p,m) ((p) |= (1<<m))
#define bit_clear(p,m) ((p) &= ~(1<<m))
#define bit_write(p,m,c) (c ? bit_set(p,m) : bit_clear(p,m))

#define wdt_set(value)   \
__asm__ __volatile__ (  \
"in __tmp_reg__,__SREG__" "\n\t"    \
"cli" "\n\t"    \
"wdr" "\n\t"    \
"sts %0,%1" "\n\t"  \
"out __SREG__,__tmp_reg__" "\n\t"   \
"sts %0,%2" \
: /* no outputs */  \
: "M" (_SFR_MEM_ADDR(_WD_CONTROL_REG)), \
"r" (_BV(_WD_CHANGE_BIT) | _BV(WDE)), \
"r" ((uint8_t) ((value & 0x08 ? _WD_PS3_MASK : 0x00) | \
_BV(WDIE) | (value & 0x07)) ) \
: "r0"  \
)

boolean set_Temperature(uint8_t temperature, boolean setTemp = false);
boolean get_saved_Massages(boolean startup = false);

void pciSetup(byte pin)
{
    *digitalPinToPCMSK(pin) |= bit (digitalPinToPCMSKbit(pin));  // enable pin
    PCIFR  |= bit (digitalPinToPCICRbit(pin)); // clear any outstanding interrupt
    PCICR  |= bit (digitalPinToPCICRbit(pin)); // enable interrupt for the group
}

void pciDisable(byte pin)
{
    *digitalPinToPCMSK(pin) &= ~bit (digitalPinToPCMSKbit(pin));  // disable pin
}
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
void loop()
{  
    unsigned long timepassed;

    static unsigned long sensorTimeOld;
    static unsigned long watchdogTimeOld;
    static unsigned long pumpTimeOld;
    static unsigned long sendTimeOld;
    static boolean sensorenLesen = true;
    static boolean wdSenden = false;
    static boolean gotoldmsg = false;
    
    if (config[nodeControll] & (1<<debugLed)){
        digitalWrite(LedPinMapping[2], LOW);
    }
    
    if (config[nodeControll] & (1<<pumpSensorVoltage)){
        timepassed = millis() - pumpTimeOld;
        if (timepassed > 3000){
            pumpTimeOld = millis();
            pump_Sensor_Voltage();
        }
    }
    
    set_Temperature(0,true);
    
    timepassed = millis() - sensorTimeOld;
    //Wir wollen die Sensoren abfragen wenn die Pausezeit vorbei ist, wenn sensorenLesen gesetzt ist, dann lesen wir sofort
    if ((timepassed > SensorPeriod) || (sensorenLesen == true)){
        //wartezeit bis die Sensoren gelesen werden koennen (DS18b20) sensorenLesen ist nur gesetzt wenn wir aus dem Sleep kommen oder die CPU neu gestartet wurde
        if ((sensorenLesen == true) && (config[digitalSensors] & (1<<readDS18))){ 
            delay(1000);
        }
        sensorTimeOld = millis();
        //Wenn eine SleepTime configuriert ist gehen wir davon aus dass die Batteriespanung auch gelesen werden soll
        if (config[sleepTime] > 0){
            read_Vcc();
        }
        if (config[digitalSensors] & (1<<readDS18)){	
            read_Dallas();
        }
        if (config[digitalSensors] & (1<<readHC05)){
            read_HC05();
        }
        if (config[digitalSensors] & (1<<readBME)){
            read_bme();
        }
        read_analog(true);
        read_counters();
        //sende aktuellen Status der Ports
        //Wir wollen die Ports zyklisch senden wenn auch die anderen Sensoren gelesen werden
        read_inputs(sensorenLesen && (!InputAlredyRead));
        //commit vom 4.11.17
        //wir lesen den Port hier nur wenn er nicht von einem interrupt behandelt wurde
        read_inputs(!InputAlredyRead);
        InputAlredyRead = false;
        sensorenLesen = false;
    }
    
    //Lesen der digitalen Inputs
    read_inputs();
    read_analog(false);
    
    //Watchdog
    timepassed = millis() - watchdogTimeOld;
    if (((timepassed > WatchdogPeriod) || (wdSenden == true)) && (WatchdogPeriod > 0)){
        watchdogTimeOld = millis();
        write_buffer_str("wd", "WD_MSG", true);
    }

    //Zum leeren des Buffers und senden aller Daten
    timepassed = millis() - sendTimeOld;    
    if (timepassed > (400 + (5 * config[nodeId]))){
        sendTimeOld = millis();
        write_buffer_str("","");
    }

    timepassed = millis() - WdTrigTimeStamp;
    if (timepassed > WdPinTimeout){
        if (!wdMsgSend){
          write_buffer_str("info","wd expiered", true);
          wdMsgSend = true;
        }
        reset_wdPins();
        SleepAlowed = true;
    }

    if (!gotoldmsg){
        //WIr holen uns die gespeicherten Nachrichten ab
        gotoldmsg = get_saved_Massages(true);
    }
    
    if((config[sleepTime] > 0) && (config[sleepTimeMulti] > 0) && SleepAlowed){
        
        // WIr holen uns die gespeicherten Nachrichten vom Gateway (Server) ab
        get_saved_Massages();
        
        //Wenn das Thermostate angeschlossen ist und der Encoder falsch steht dann zeigen wir das mit Led3 an dazu muss evtl die Sperre ausgeschaltet werden
        if (config[digitalOut] & (1<<lockThermostate)){
            pinMode(signalB, INPUT);
        }        
        if (ShowLeds && ThermostatPresent){
            delay(10);
            ShowLeds = false;
            if (digitalRead(signalA) == LOW || digitalRead(signalB) == LOW){
                // Wir schalten die rote Led ein
                digitalWrite(LedPinMapping[0], HIGH);
                delay(30);
                digitalWrite(LedPinMapping[0], LOW);
            }else{
                // Wir schalten die gruene Led ein
                digitalWrite(LedPinMapping[2], HIGH);
                delay(30);
                digitalWrite(LedPinMapping[2], LOW);            
            }
        }
        if (config[digitalOut] & (1<<lockThermostate)){
            pinMode(signalB, OUTPUT);
        }        
        //Die Temperatur einstellen (die Funktion braucht etwas länger)
        set_Temperature(0,true);
        //Wenn der Watchdog im letzten Schritt nicht getriggert wurde dann rufen wir den Sleep auf
        if (SleepAlowed){
            if (config[nodeControll] & (1<<debugLed)){
                digitalWrite(LedPinMapping[2], LOW);
            }
            // Wenn das configBit sendAgain gesetzt ist wollen wir nach einer wdPeriode wieder aufwachen und erneut senden
            if (config[nodeControll] & (1<<sendAgain)){
                boolean sendAgainOk;
                sendAgainOk = write_buffer_str("","");
                go_sleep(!sendAgainOk);
                sensorenLesen = sendAgainOk;
                wdSenden = sendAgainOk;
            }else{
                //Zum leeren des Buffers und senden aller Daten vor dem Sleep
                write_buffer_str("","");
                go_sleep();
                sensorenLesen = true;	//Wir wollen, dass die Sensoren sofort gelesen werden
                wdSenden = true;		//Wir wollen, dass der Watchdog sofort gesendet wird
            }
        }
    }

    if((config[sleepTime] == 0) || (config[sleepTimeMulti] == 0)){
        radio_Rx_loop();
    }

    if (config[nodeControll] & (1<<debugLed)){
        digitalWrite(LedPinMapping[2], HIGH);
    }
    
}//end loop

ISR (PCINT0_vect)
{
    cli();
    //debounce switch
    delay(2);
    sei();
    sleep_disable();        // first thing after waking from sleep:
    boolean oldSendAlowed = SendAlowed;
    SendAlowed = false;
    read_inputs();
    InputAlredyRead = true;
    SendAlowed = oldSendAlowed;
    PCinterrupt = true;
}

ISR (PCINT1_vect)
{
    cli();
    //debounce switch
    delay(2);
    sei();
    sleep_disable();        // first thing after waking from sleep:
    boolean oldSendAlowed = SendAlowed;
    SendAlowed = false;
    read_inputs();
    InputAlredyRead = true;
    SendAlowed = oldSendAlowed;
    PCinterrupt = true;
}

ISR (PCINT2_vect)
{
    cli();
    //debounce switch
    delay(2);
    sei();
    sleep_disable();        // first thing after waking from sleep:
    boolean oldSendAlowed = SendAlowed;
    SendAlowed = false;
    read_inputs();
    InputAlredyRead = true;
    SendAlowed = oldSendAlowed;
    PCinterrupt = true;
}

ISR (WDT_vect)
{
    sleep_disable();        // first thing after waking from sleep:
}

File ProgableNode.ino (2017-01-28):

/*
Author:  Eric Tsai
License:  CC-BY-SA, https://creativecommons.org/licenses/by-sa/2.0/
Date:  7-21-2014
File: Mailbox.ino
This sleeps until interrupted, then sends data via RFM69

Modifications Needed:
1)  Update encryption string "ENCRYPTKEY"
2)  
*/


//Basic Defines  --------------------------------------------------------------------------------------------------
#include <RFM69.h>
#include <SPI.h>
//#include <eeprom.h>

//Standardkonfig wird uebernommen wenn JP_2 == GND oder funktion_pin0 == 255 (Komando "w_0":"255")
#define DEFAULTNODEID        250    //unique for each node on same network
#define DEFAULTNETWORKID     146  //the same on all nodes that talk to each other
#define DEFAULTGATEWAYID     1
#define DEFAULTENCRYPTKEY    "sampleEncryptKey" //exactly the same 16 characters/bytes on all nodes!

//Match frequency to the hardware version of the rfm69 on your Moteino (uncomment one):
#define FREQUENCY   RF69_433MHZ
//#define FREQUENCY   RF69_868MHZ
//#define FREQUENCY     RF69_915MHZ
//#define IS_RFM69HW    //uncomment only for RFM69HW! Leave out if you have RFM69W!
#define ACK_TIME		30 // max # of ms to wait for an ack
#define LED_1			5  //optinonal to Power >3V sensors from 1.8V batt voltage: Write 0/1/0/1 to pump Power for external sensors (and switch on LED_2)
#define LED_2			6 //optinonal to Power >3V sensors from 1.8V batt voltage: Power for external Sensors
#define LED_3			7 
#define ResetRfmPin		2
//you can use the analog pins as digital pins, by numbering them 14 - 19
//Analog Input PC0-PC5
#define JP_1		  16 //PC2 
#define JP_2		  15 //PC1
#define RFM_POWER_LEVEL 31



char sendBuffer[RF69_MAX_DATA_LEN] ;
uint8_t sendBufferLength;
RFM69 rfm69;

//end Basic Defines ---------------------------------------------------------------------------------------------------


//Board Defines--------------------------------------------------------------------------------------------------------
#include <DHT.h>
#include <OneWire.h>
#include <DallasTemperature.h>
#include <Adafruit_Sensor.h>
#include <Adafruit_BME280.h>

//device DHT11 Temperature/Humidity
	#define DHTPIN 16     // what pin we're connected to
	#define DHTTYPE DHT11   // DHT 11 
	DHT dht(DHTPIN, DHTTYPE);

// device DS18B20
	#define ONE_WIRE_BUS 9
	OneWire oneWire(ONE_WIRE_BUS);
	DallasTemperature dallas(&oneWire);
	
//BME280 I2C
	#define SEALEVELPRESSURE_HPA (1013.25)
	Adafruit_BME280 bme;
	
//ADC6 atmega voltage, to measure switch on Port 6 
	#define atVolage		6
	
//Pins to Power Sensor
	#define pumpPin			6
	#define supplyPin		5
	
//device ultrasonic
	#define HC05pingPin 	0
	#define HC05trigPin		1

#define SERIAL_BAUD 9600


unsigned long WatchdogPeriod;
unsigned long SensorPeriod;
unsigned long SleepTime;


//end Board Defines ---------------------------------------------------------------------------------------------------


#define configSize 28

uint8_t eeConfig[configSize] EEMEM;
uint8_t config[configSize];
uint8_t eeEncryptKey[16] EEMEM;
boolean check_watchdog_req =0;

//Bits der Variablen funktion_pin..
#define in_out				0	//DDR wie im Atmel Datenblatt 0=in
#define port				1	//PORT wie im Atmel Datenblatt
#define pcInt				2
#define pwm					3
#define wdinvert			4	//0==Pin High wenn Wd -> OK
#define wdreq				5	//Watchdog fuer diesen Pin ein
#define readInput			6
//debounce ??

//Bits der Variablen math_analog..
#define  readPlaint			0
#define  readLDR			1
#define  readRain			2

//Bits der Variable digitalsensors
#define  readDS18			0
#define  readHC05			1
#define  readBME			2
#define	 readDHT			3

//Bits der Variable digitalOut
#define	 writeWsLed			0

//Bits der Variable nodeControll
#define sensorPower			0
#define pumpSensorVoltage	1
#define uart				2
#define i2c					3
#define dmx					4

//Bytes des Config/outConfig Arrays (outConfig nur fuer Dio Pins 0-usedDio)
#define  funktion_pin0		0
#define  funktion_pin1		1
#define  funktion_pin17		2
#define  funktion_pin18		3
#define  funktion_pin19		4
#define  funktion_pin9		5
#define  funktion_pin16		6

#define	 math_analog2		10
#define	 math_analog3		11
#define  math_analog4		12
#define  math_analog5		13
#define	 digitalSensors		15
#define  digitalOut			16

#define  nodeControll		20
#define  sleepTimeMulti		21		//sleepTime Multiplicator
#define  sleepTime			22		//Sleep time in Sekunden
#define  watchdogDelay		23		//watchdog in * 5 sec
#define  nodeId				24
#define  networkId			25
#define  gatewayId			26
#define  sensorDelay		27		//Messpause der Sensoren in *10 sec

//config[] == 0-9Dio, 10-14analog
//Max of usedDio is 8 see read_inputs()
#define usedDio				7
//#define usedAnalog			3
const uint8_t pinMapping[15]{0,1,17,18,19,9,16,0,0,0,3,4,5,0,0};
//der SSPin macht noch Probleme Spi funktioniert dann nicht mehr!
//const uint8_t pinMapping[15]{0,1,17,18,19,9,10,0,0,0,3,4,5,0,0};

#define bit_set(p,m) ((p) |= (1<<m))
#define bit_clear(p,m) ((p) &= ~(1<<m))
#define bit_write(p,m,c) (c ? bit_set(p,m) : bit_clear(p,m))

void pciSetup(byte pin)
{
	*digitalPinToPCMSK(pin) |= bit (digitalPinToPCMSKbit(pin));  // enable pin
	PCIFR  |= bit (digitalPinToPCICRbit(pin)); // clear any outstanding interrupt
	PCICR  |= bit (digitalPinToPCICRbit(pin)); // enable interrupt for the group
}

void initVariables(void)
{
	//Standard config laden
	//Alle Pins auf Eingang
	//keine Sensoren aktiv
	//es kann bei der ersten Inbetriebnahme zu Problemen (haengt beim Sensor lesen) kommen wenn diese Variable nicht auf 255 steht
	//if ((eeprom_read_byte(&eeConfig[funktion_pin0]) == 255) || !getJumper()){
	if (eeprom_read_byte(&eeConfig[funktion_pin0]) == 255){
	//if (1){
		for (uint8_t i = 0; i < configSize-4; i++){
			eeprom_write_byte(&eeConfig[i], 0);
		}
		eeprom_write_byte(&eeConfig[nodeId], DEFAULTNODEID);
		eeprom_write_byte(&eeConfig[networkId], DEFAULTNETWORKID);
		eeprom_write_byte(&eeConfig[gatewayId], DEFAULTGATEWAYID);
		eeprom_write_byte(&eeConfig[sensorDelay], 2);	
		//eeprom_write_block(eeEncryptKey, DEFAULTENCRYPTKEY, 16);
	}
	
	for (uint8_t i = 0; i < configSize; i++){
		config[i] = eeprom_read_byte(&eeConfig[i]);
	}
	
	SleepTime = config[sleepTime] * config[sleepTimeMulti] * 1000;
	SensorPeriod = config[sensorDelay] * 10000;
	WatchdogPeriod = config[watchdogDelay] * 5000;
	
	for (uint8_t i =0; i < usedDio; i++){
		check_watchdog_req|= config[i] & (1<<wdreq);
	}
}

void check_improveConfig(void){
		
		
			
}
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

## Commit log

2017-01-29 Erste Implementierung des Sleep Modes
2017-01-29 Parameter resetBuffer aus write_buffer_str entfernt
    [ProgableNode.ino]
2017-02-01 Lesen der Batterie Spannung
2017-02-01 Sensor Power Pins modifiziert
2017-02-01 Fix Pin Interrupt
2017-02-01 Handling von BreakSleep, RFM RX Mode, analog Sensors geändert
2017-02-02 Format des MQTT Strings angepasst, Erster Entwurf von readAnalog, PinMapping geändert,
2017-02-02 Defines mit Kommentaren versehen und teils verändert
2017-02-08 DS18b.. Sensor lesen verbessert. Ungetestet
2017-02-09 Batteriespannung wird jetzt genauer gemessen
2017-02-10 Verhalten der Leds verändert
2017-02-12 SSD1306 128x64 und 64x48 Unterstützung eingebaut
2017-02-19 Internal Oscillator Calibration hinzugefügt
    [ProgableNode.ino]
2017-02-19 Board und Programmer Defines hinzugefügt
2017-02-19 BME Sensor altitude entfernt
2017-02-21 Kommentare und Code aufgeräumt
2017-02-21 Platine hinzugefügt
    [Bestueckung1.gbr, Bohren.drl, Kupfer1.GBR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]
2017-02-26 Schaltplan Print Version hinzugefügt
2017-02-26 Sensor Versorgung und Display Sleep eingebaut
2017-03-02 Funktion zum Temperatur einstellen hinzugefügt
2017-03-02 Debug Leds sind jetzt abschaltbar
2017-03-02 Reset per jumper verbessert
    [ProgableNode.ino]
2017-03-03 Kommentare und serial.begin verbessert
2017-03-04 Ws Led entfernt, toleranz oscCal angespasst
2017-03-05 DHT Sensor entfernt
2017-03-05 Temperatur einstellung für Thermostate verbessert
2017-03-05 Watchdog wird anders gesetzt
2017-03-05 Led blinken beim Start und PinConfig nacheinnander schreiben
2017-03-12 Pin Mapping ist jetzt wie auf der Platine
2017-03-12 Status der Pins wird jetzt auch zyklisch mit gesendet
2017-03-12 Poll Time zum warten auf daten verlängert und toleranz für internen osc erhöht
2017-03-26 Gehäuse hinzugefügt
    [Deckel Display.FCStd, Deckel Display.stl, Deckel Node1.FCStd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]
2017-04-05 Interrupt RIsing und Interrup Falling eingebaut sowie einen Counter für Eingänge (S0)
2017-04-20 Subscribe und unsubscribe request geändert
2017-04-20 diverse änderungen command 19, gleiche standard node Id wie die Node
2017-04-23 Gehäuse für die PIR BME280 touch Node hinzugefügt
    [Deckel_3AAA_PIR_Node.FCStd, Deckel_3AAA_PIR_Node.stl, Gehause HC-SR501.FCStd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]
2017-04-23 Gehäuse für das WEMOS RGB Licht hinzugefügt
    [Gehause 4x4Led WEMOS Panel.FCStd, Gehause 4x4Led WEMOS Panel.stl]
2017-05-04 Bilder hinzugefügt
    [Deckel_2AAA_Node.stl, Deckel_2AAA_PIR_Node.FCStd]
2017-05-05 fix eeprom init und osccal mit watchdog überwachen
    [ProgableNode.ino]
2017-05-05 Kommando an das Gateway gefixt
    [Gehause Node1.stl]
2017-05-05 Fotos hinzugefügt und readme geändert
2017-05-05 2AAA und 3AAA Node Gehäuse hinzugefügt
    [Deckel_2AAA_Node.FCStd, Gehause_2AAA_Node.FCStd, Gehause_2AAA_Node.stl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]
2017-05-11 fix encryptkey Setting, led blink hinzugefügt, readAll config Data hinzugefügt
    [ProgableNode.ino]
2017-06-10 fix 5 degree bug
    [ProgableNode.ino]
2017-06-10 add voltage reading
2017-11-04 Add UltraLow Power Sleep
2017-11-04 Add switch debounce
2017-11-04 fix doublicated port status message
    [ProgableNode.ino]
2017-12-30 Led Pin Mapping geändert /hinzugefügt
2017-12-30 Led pin Mapping additional commit
2017-12-30 fix som little bugs
    [ProgableNode.ino]
2017-12-30 Add some funktions for Thermostat Encoder Controll, led blink if enc is in wrong pos, funktion to lock enc
    [ProgableNode.ino]
2018-01-07 reset der Node nicht bei allen config reg nötig, node abmelden vor einem Neustart
    [ProgableNode.ino]
2018-01-07 bugfix Led blinken lassen wenn das Encoderrad falsch steht
    [ProgableNode.ino]
2018-01-07 Bugfix config Nummer wurde nicht gesendet wenn config geändert wurde
    [ProgableNode.ino]
2018-03-11 adding new board, messing up
    [Bestueckung1.gbr, Bohren.drl, Drill.drl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]
2018-04-05 Bugfix: wake node was reported sleeping state to GW
    [ProgableNode.ino]
2018-08-27 Fix DS18b20 Sensor bug
    [ProgableNode.ino]
2018-08-27 Funktion to debounce switches
2018-08-27 modify timers witout restart bugfix
    [ProgableNode.ino]
2019-10-17 Add fuel high Sensor with pressure Sensor
2019-10-17 Add watchog to fix low battery bug
    [ProgableNode.ino]
2019-10-17 change syntax for ds18b20 sensor
2020-01-13 Add Board ArduinoSPS
2020-01-13 ADC sends now immediately if a change occours
2020-01-13 Try to fix some collisions
    [ProgableNode.ino]
2020-01-15 Fix some radio collisions
    [ProgableNode.ino]
2020-02-21 add some Housings
    [Deckel_CR2477_Node.FCStd, Deckel_CR2477_Node.stl, Deckel_CR2477_Node2.FCStd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]
2020-05-02 Change Sensor Supply Pin and fix Watchdog Bug
    [ProgableNode.ino]
2020-07-09 fix sensor period bug
    [ProgableNode.ino]
2020-07-09 Add an correct Firmware Commit
    [ProgableNode.ino]
2021-03-13 Fix some little bugs
    [ProgableNode.ino]
